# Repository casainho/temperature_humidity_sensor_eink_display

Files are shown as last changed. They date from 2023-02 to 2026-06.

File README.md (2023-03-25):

# DIY Temperature and Humidity sensor using EInk display

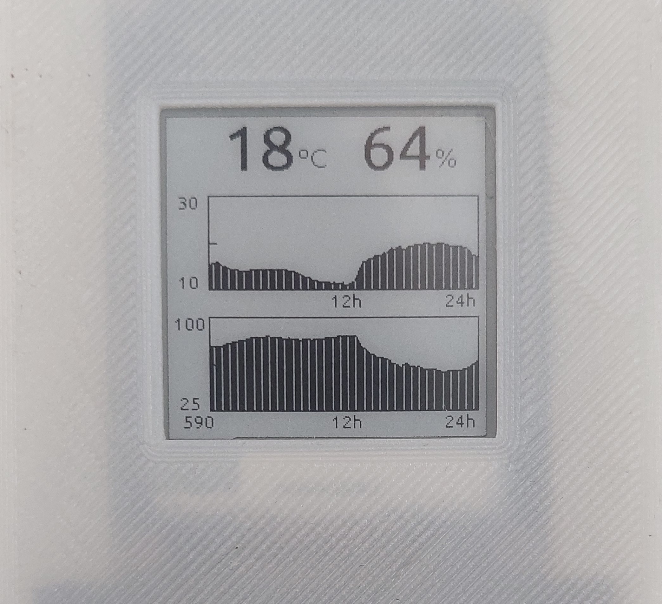
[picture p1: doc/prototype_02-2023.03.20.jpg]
[](doc/prototype_02-2023.03.20.jpg)
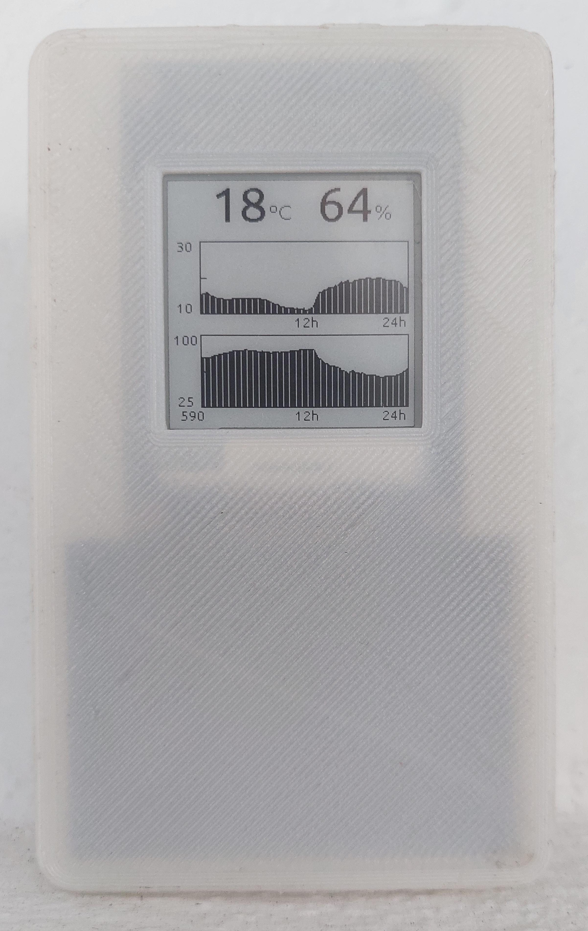
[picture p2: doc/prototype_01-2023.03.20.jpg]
[](doc/prototype_01-2023.03.20)

This is a simple DIY Temperature and Humidity sensor, with a small EInk display and (future) integration with Home Assistant.

**Features:**
  * shows the numeric value of temperature and relative humidity (measured at every 10 minutes)
  * shows two graphs with the temperature and relative humidity (measured at every 10 minutes), from the last 24h
  * PLANNED: [Send temperature and relative humidity to HomeAssistant](https://learn.adafruit.com/temperature-and-humidity-sensing-in-home-assistant-with-circuitpython)

**Main characteristics:** 
* Easy DIY, OpenSource and easy repairable
* Uses the factory calibrated temperature and humidity sensor AHT21
* The display is a 1.54 inches EInk display
* The microcontroller board is the ESP32-S2, running Pyhton (CircuitPython) firmware
* The systemn runs from a USB-C cable or from some other power supply source like 3xAAA NiMh batteries, as there is a DC-DC boost converter that supports input voltage from 1V up to 5V, and outputs a fixed 5V

All the components were bought on Aliexpress.

## Pictures

Pictures from prototype on 2023.02.22.

Showing the temperature and humidity values:<br>
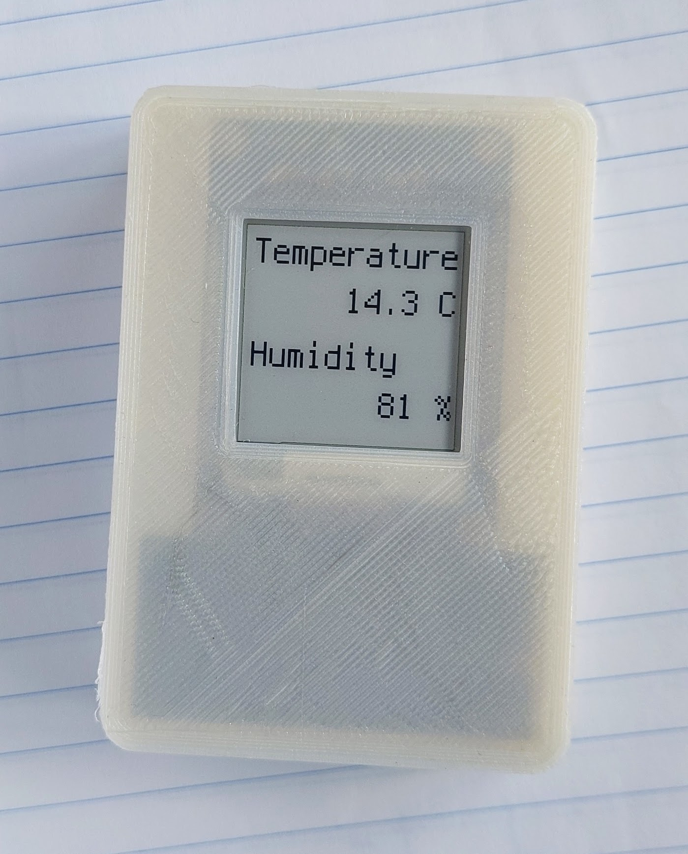
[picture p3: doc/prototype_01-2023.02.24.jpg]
[](doc/prototype_01-2023.02.24.jpg)

Details of the 3D printed enclosure:<br>
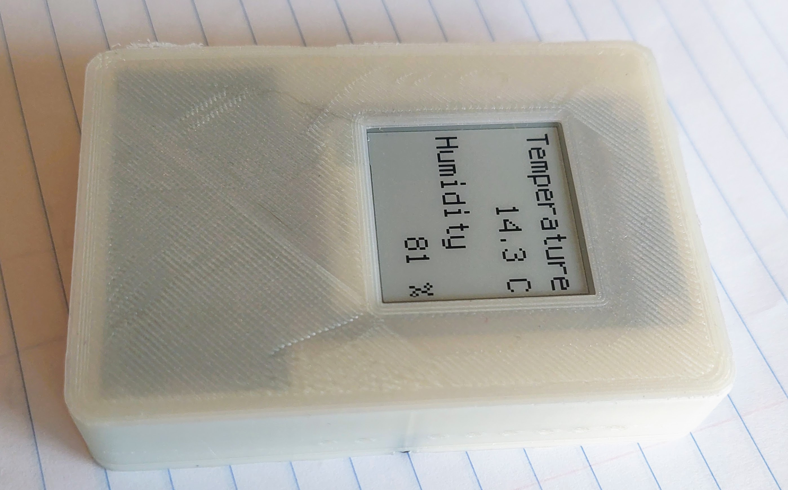
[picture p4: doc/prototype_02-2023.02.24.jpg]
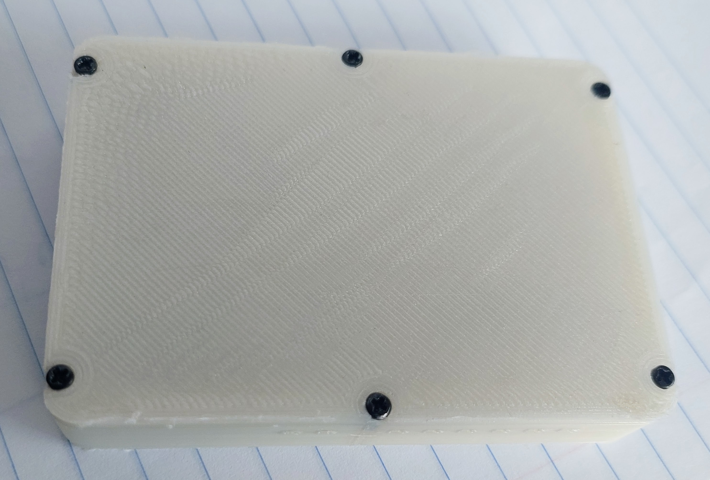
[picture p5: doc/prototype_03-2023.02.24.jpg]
[](doc/prototype_02-2023.02.24.jpg) [](doc/prototype_03-2023.02.24.jpg)

Details of the DIY electronics:<br>
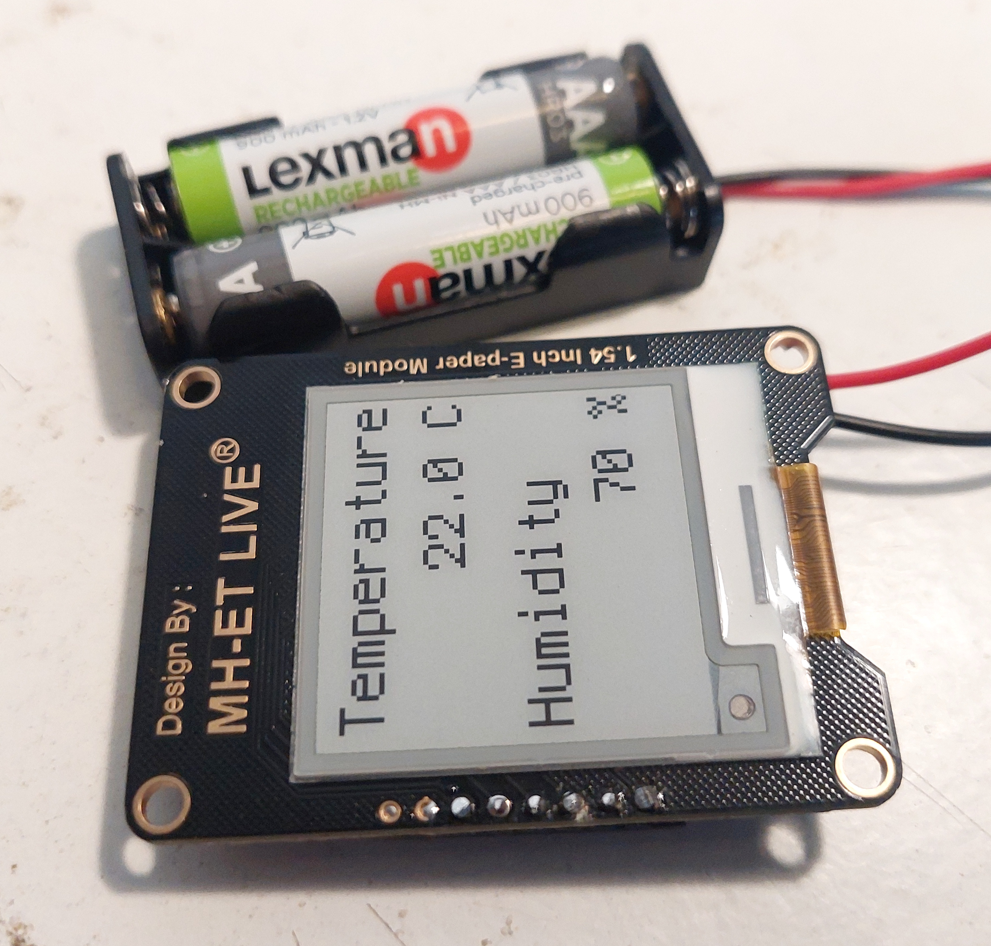
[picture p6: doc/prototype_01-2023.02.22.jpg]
[](doc/prototype_01-2023.02.22.jpg)

Details of the DIY build. Black board is the 1.54 inches EInk display, the purple board is the ESP32-S2 board (Lolin S2 Mini), the blue board is the AHT21 sensor and the green board is a DC-DC boost converter module that transforms the 2.4V from the NiMH batteries to 5V to power the ESP32-S2 board and all other components:<br>
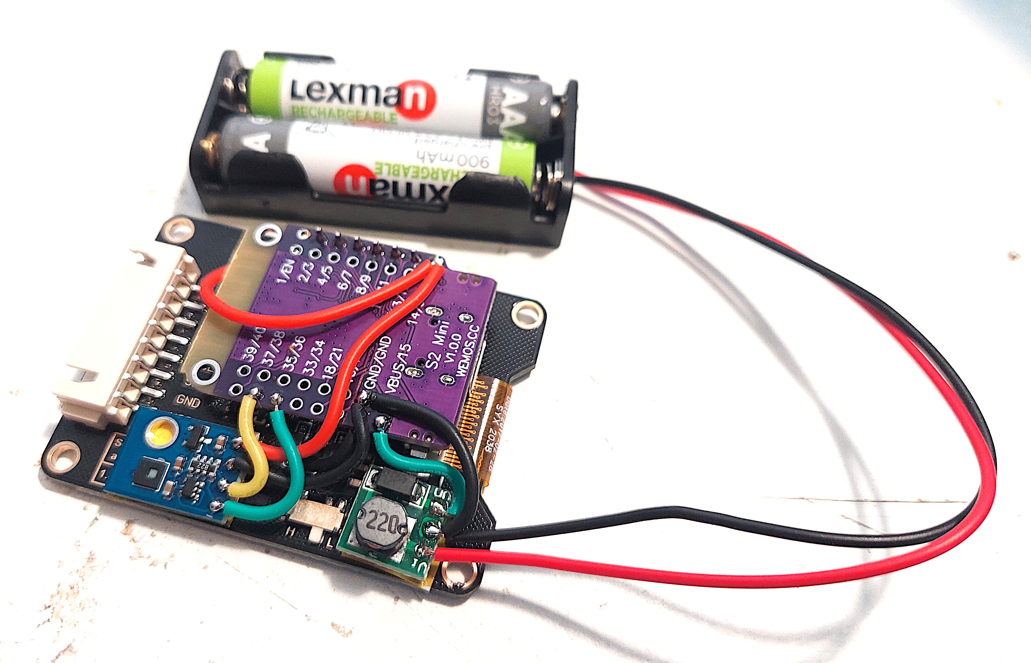
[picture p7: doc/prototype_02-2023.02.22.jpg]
[](doc/prototype_02-2023.02.22.jpg)

## Tecnhical information
* the 3D printed enclosure was designed in [FreeCAD](https://www.freecad.org/)
* the firmware is developed in [CircuitPython](https://circuitpython.org/)
* the graphs are implemented using the [uplot library](https://github.com/jposada202020/CircuitPython_uplot)

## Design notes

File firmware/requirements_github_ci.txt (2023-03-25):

adafruit-circuitpython-bitmap-font
adafruit-circuitpython-busdevice
adafruit-circuitpython-display_shapes
adafruit-circuitpython-display_text
circuitpython_uplot

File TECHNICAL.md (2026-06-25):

# DIY CO2 Monitor with ESP32-C3, SCD41 and E-Ink Display

This is a simple DIY indoor air quality monitor based on an **ESP32-C3**, a **Sensirion SCD41** sensor and a small **E-Ink display**.

The device is designed to periodically measure real CO2 concentration, temperature and relative humidity, show the latest values on the display, and then enter a low-power sleep mode to save battery.

The project is intended to be:

* easy to build;
* open source;
* repairable;
* battery powered;
* low power;
* suitable for indoor air quality monitoring.

## Features

* Measures real CO2 concentration using the Sensirion SCD41 sensor.
* Measures temperature and relative humidity.
* Shows the latest readings on a 1.54 inch E-Ink display.
* Uses an ESP32-C3 microcontroller.
* Firmware written in MicroPython.
* Designed for low-power operation using deep sleep.
* Powered from NiMH batteries through a 3.3 V DC-DC buck converter.
* Uses a DD2712SA 3.3 V buck converter module.
* Periodic measurement and display update.
* Future option: send measurements to Home Assistant.

## Main characteristics

* Microcontroller: ESP32-C3.
* Sensor: Sensirion SCD41.
* Display: 1.54 inch E-Ink display.
* Firmware: MicroPython.
* Power supply: NiMH batteries.
* DC-DC converter: DD2712SA 3.3 V buck converter.
* Operating mode: wake up, measure, update display, deep sleep.
* Typical update interval: 5 minutes.

---

# Hardware

## Hardware overview

The hardware architecture is:

```text
4x NiMH batteries
   |
   |---- Power switch
   |
DD2712SA 3.3 V buck converter
   |
   +---- ESP32-C3
   +---- Sensirion SCD41
   +---- E-Ink display
```

## Main components

| Component | Description |
| --- | --- |
| ESP32-C3 | Main microcontroller running the MicroPython firmware |
| Sensirion SCD41 | CO2, temperature and humidity sensor |
| E-Ink display | Low-power display for showing the latest values |
| DD2712SA 3.3 V | DC-DC buck converter used to generate the 3.3 V supply rail |
| 4x NiMH batteries | Rechargeable battery pack |
| Power switch | Main power switch |
| Capacitors | Used to stabilize the 3.3 V rail during current peaks |

## ESP32-C3

The project uses an **ESP32-C3** microcontroller.

The ESP32-C3 is responsible for:

* controlling the complete device;
* communicating with the SCD41 sensor using I2C;
* updating the E-Ink display;
* measuring the battery voltage, if implemented;
* managing the sleep/wake cycle;
* running the MicroPython firmware.

## Sensor

The project uses the **Sensirion SCD41** sensor.

The SCD41 measures:

* CO2 concentration, in ppm;
* temperature, in degrees Celsius;
* relative humidity, in percent.

The sensor communicates with the ESP32-C3 using I2C.

## Power supply

The device is powered from rechargeable **NiMH batteries**.

The recommended power architecture is:

```text
4x NiMH batteries
   |
DD2712SA 3.3 V buck converter
   |
3.3 V system rail
```

The DD2712SA 3.3 V module converts the battery voltage to a regulated 3.3 V supply for the ESP32-C3, SCD41 and E-Ink display.

---

# Firmware

## Firmware overview

The firmware is written in **MicroPython**.

The main firmware goal is to:

1. wake up from deep sleep;
2. initialize the required peripherals;
3. read the SCD41 sensor;
4. update the E-Ink display;
5. optionally measure battery voltage;
6. enter deep sleep again.

## Main firmware cycle

```text
Boot
  |
Initialize I2C
  |
Initialize SCD41
  |
Read CO2, temperature and humidity
  |
Read battery voltage
  |
Update E-Ink display
  |
Prepare peripherals for low-power mode
  |
Enter deep sleep
  |
Wake up after configured interval
```

## Suggested firmware structure

A modular MicroPython firmware structure is recommended:

```text
main.py
config.py
scd41.py
display.py
battery.py
power.py
```

## main.py

Main entry point.

Responsibilities:

* load configuration;
* initialize hardware;
* call the sensor reading functions;
* update the display;
* decide the next sleep interval;
* enter deep sleep.

## config.py

Project configuration.

Example:

```python
SLEEP_MINUTES = 5

I2C_SCL_PIN = 9
I2C_SDA_PIN = 8

BATTERY_CELLS = 4
LOW_BATTERY_VOLTAGE = 4.2
CRITICAL_BATTERY_VOLTAGE = 4.0

DISPLAY_ROTATION = 0
USE_WIFI = False
```

The exact I2C pins should be adjusted according to the ESP32-C3 board being used.

## scd41.py

SCD41 handling.

Responsibilities:

* initialize the SCD41 sensor;
* start measurements;
* wait until data is ready;
* read CO2, temperature and humidity;
* return a structured data object.

Example returned values:

```python
{
    "co2_ppm": 820,
    "temperature_c": 22.4,
    "humidity_percent": 54.0
}
```

## display.py

E-Ink display handling.

Responsibilities:

* initialize the display;
* draw the static layout;
* show CO2, temperature and humidity;
* show battery state;
* show warning messages;
* refresh the display.

Suggested status messages:

| CO2 level | Display status |
| ---: | --- |
| Below 800 ppm | Good |
|  800 to 1200 ppm | Ventilation recommended |
| 1200 to 2000 ppm | Poor air quality |
| Above 2000 ppm | Ventilate urgently |

## battery.py

Battery measurement and classification.

Responsibilities:

* read the ADC value;
* convert ADC reading to battery voltage;
* classify battery state;
* return battery voltage and status.

## power.py

Low-power handling.

Responsibilities:

* turn off unused peripherals when possible;
* disable Wi-Fi if not needed;
* prepare the ESP32-C3 for deep sleep;
* configure the wake-up timer.

Recommended approach:

* keep Wi-Fi disabled by default;
* keep active time as short as possible;
* avoid permanent LEDs;
* avoid unnecessary display refreshes;
* use deep sleep between measurements.

---

# Technical information

* The enclosure was designed in [FreeCAD](https://www.freecad.org/).
* The firmware is written in [MicroPython](https://micropython.org/).
* The microcontroller is an ESP32-C3.
* The display is a 1.54 inch E-Ink display.
* The CO2 sensor is the Sensirion SCD41.
* The power converter is the DD2712SA 3.3 V buck converter.
* The system is designed for periodic measurements and low-power sleep operation.

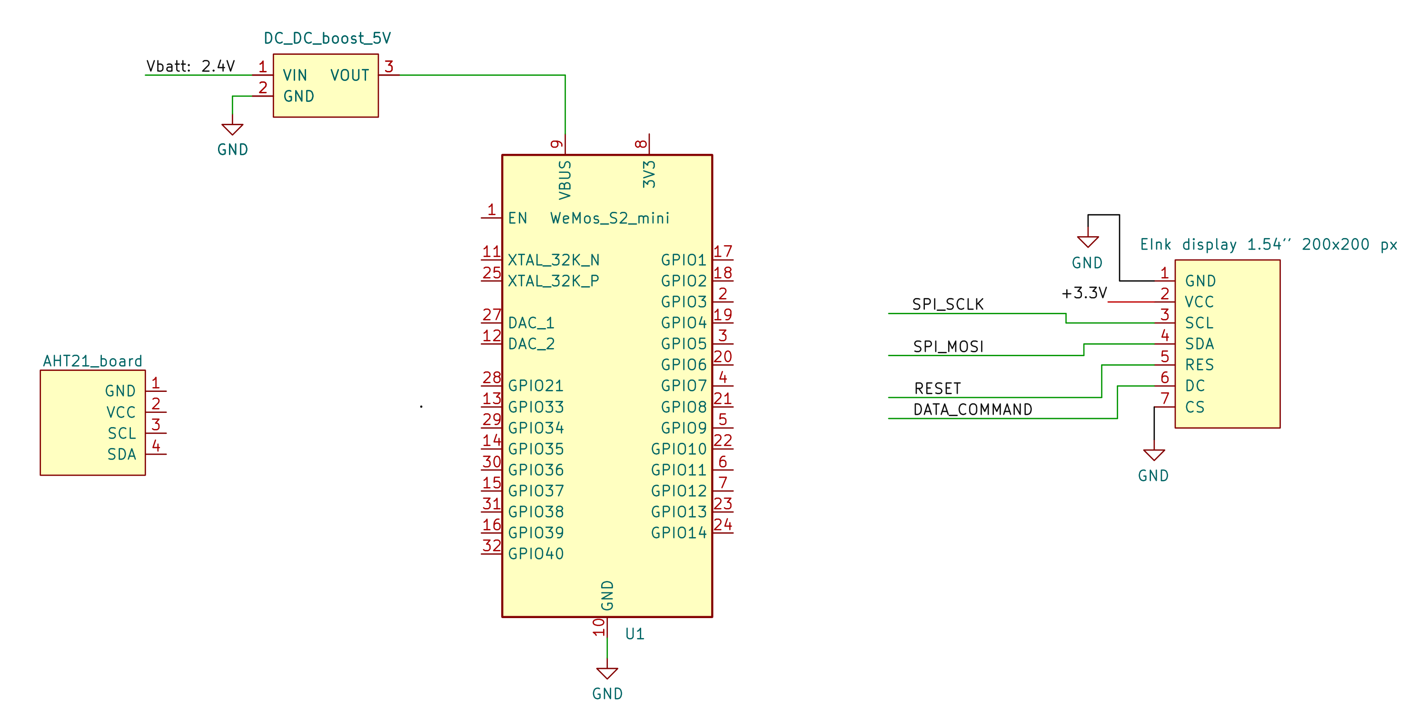
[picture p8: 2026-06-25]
hardware/schematic.png

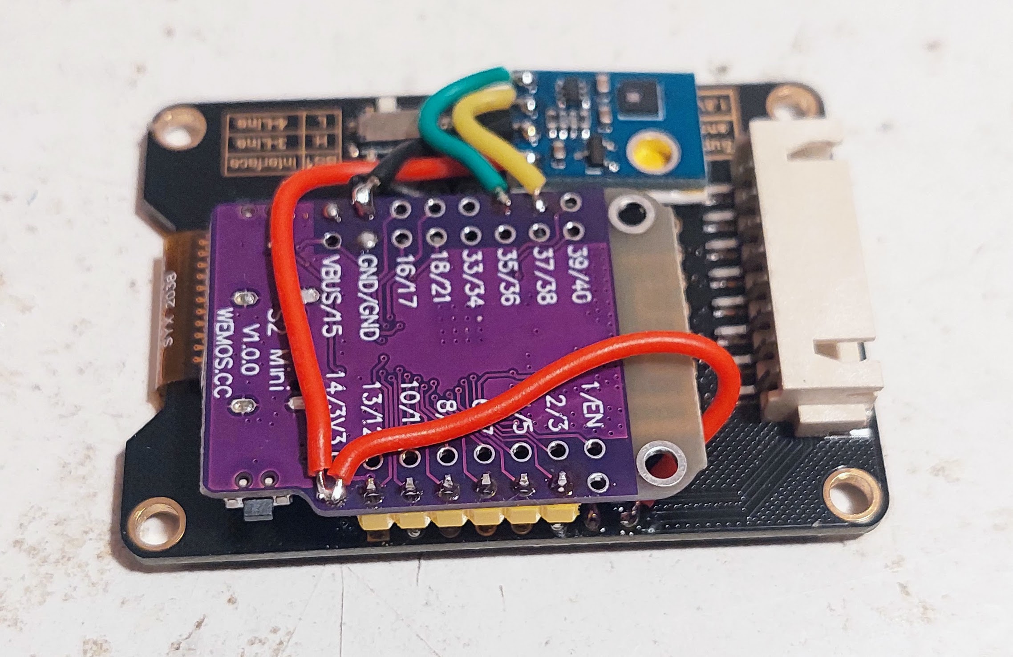
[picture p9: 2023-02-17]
doc/prototype_04-2023.02.17.jpg

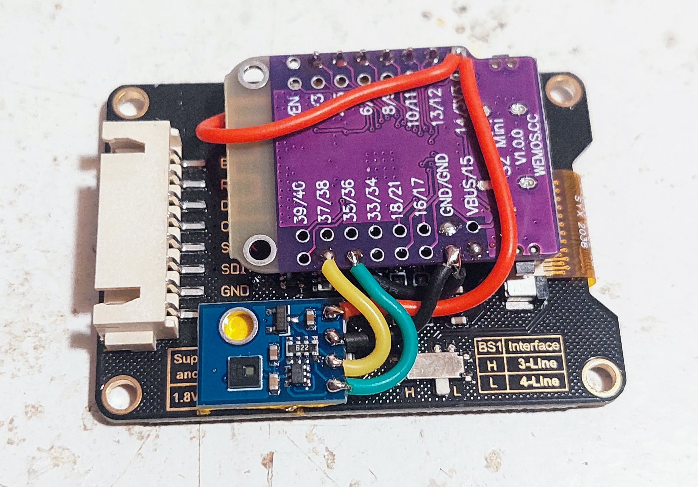
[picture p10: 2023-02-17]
doc/prototype_03-2023.02.17.jpg

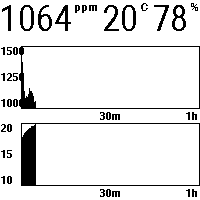
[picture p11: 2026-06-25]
latest_screen.png

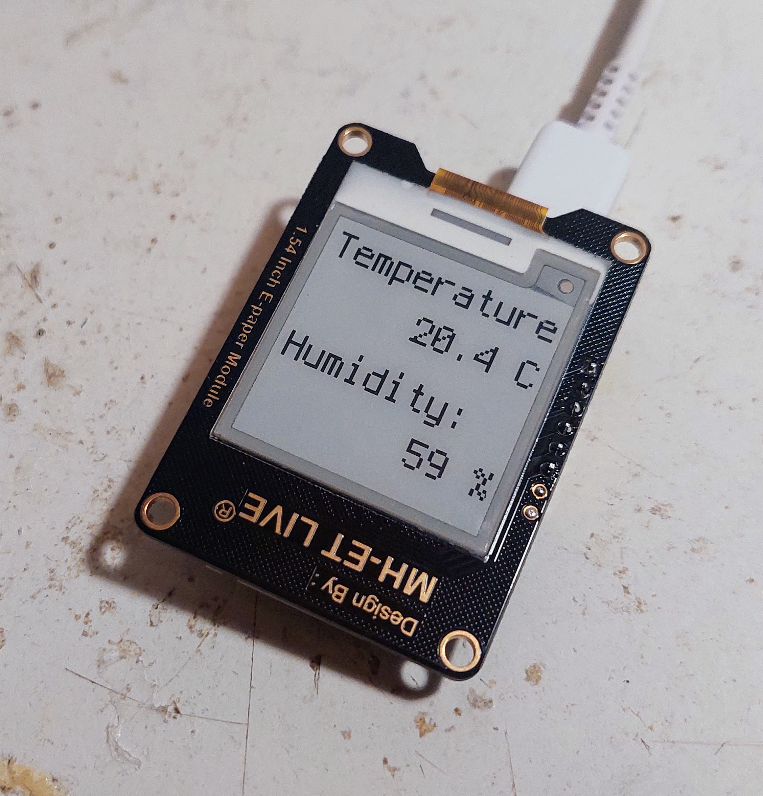
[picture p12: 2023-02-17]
doc/prototype_05-2023.02.17.jpg

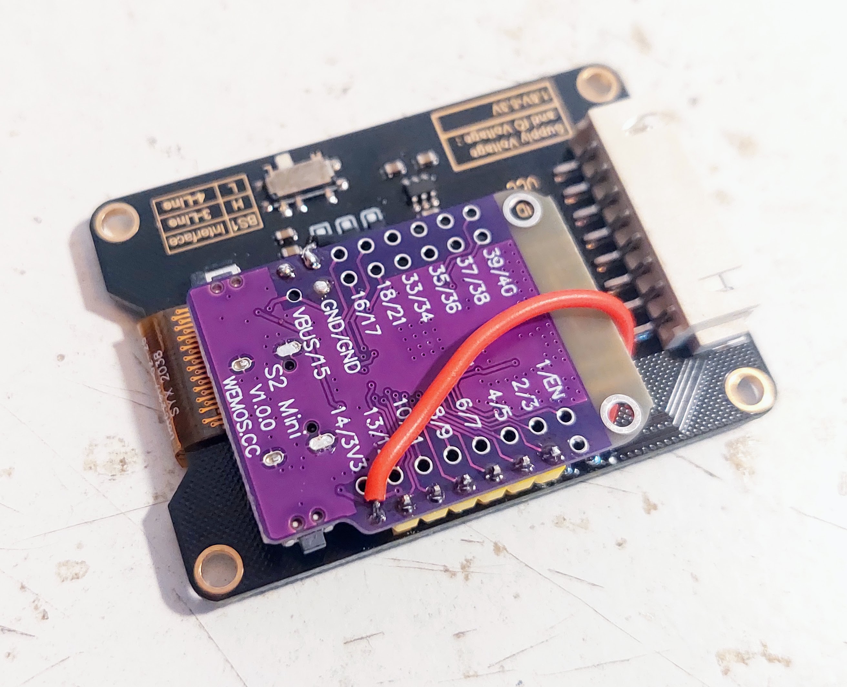
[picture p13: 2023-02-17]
doc/prototype_02-2023.02.17.jpg

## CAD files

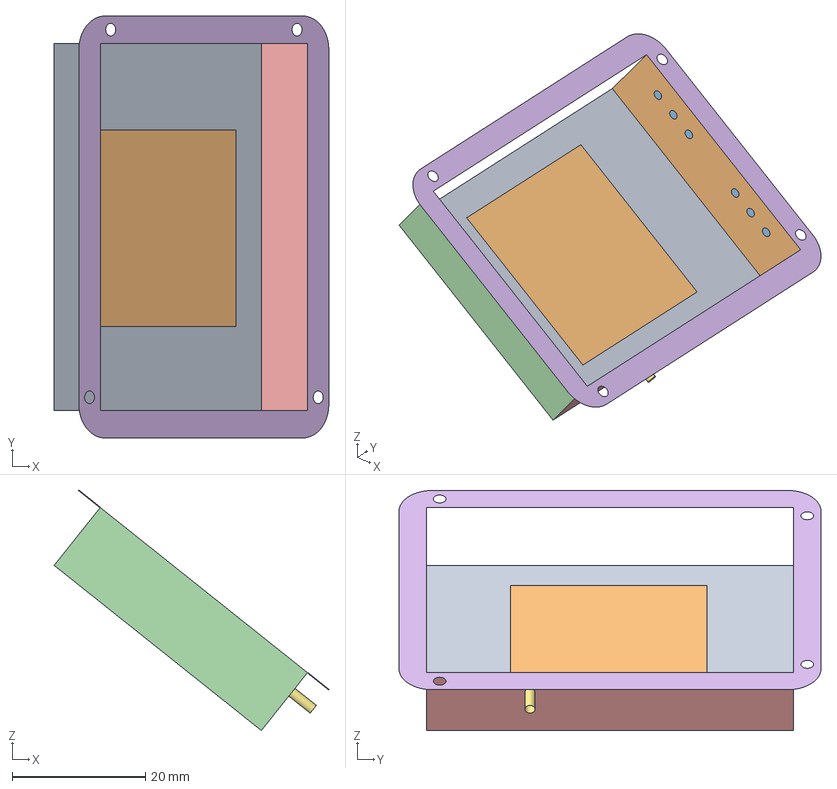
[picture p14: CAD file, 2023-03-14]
3d_print_enclosure/sensor-assembly3.FCStd
41.2 x 63.3 x 36.0 mm
_Element
_Element001
_Element003
_Element006
_Element008
_Element019
_Element028
_Element035
_Element036
_Element041
_Element042
_Element043

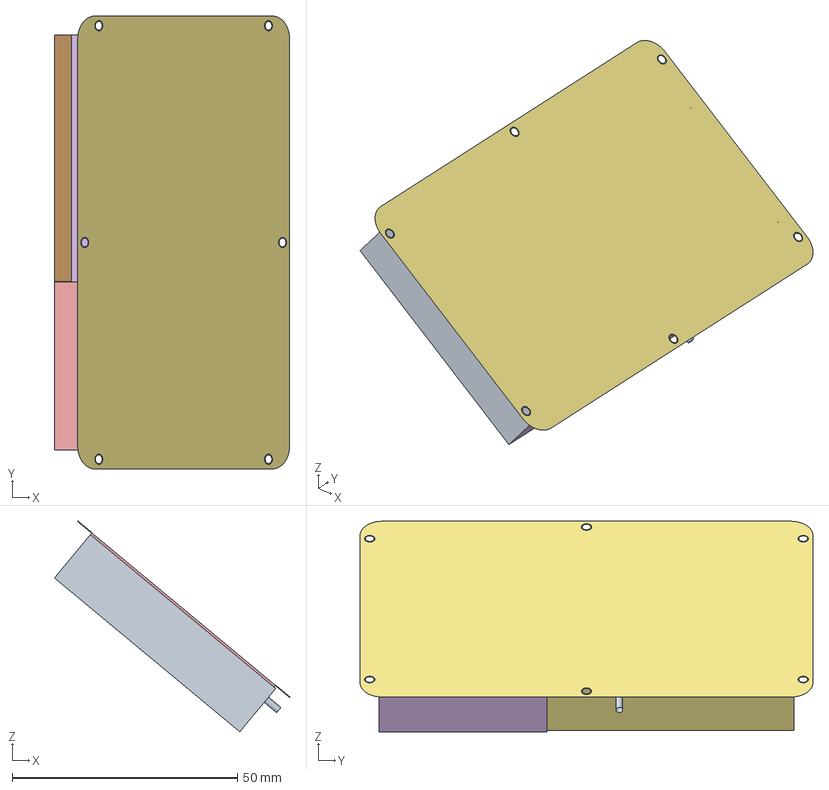
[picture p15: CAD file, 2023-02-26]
3d_print_enclosure/enclosure_with_3x_aaa_nihm/sensor-assembly3.FCStd
52.2 x 100.6 x 46.8 mm
_Element
_Element001
_Element002
_Element003
_Element006
_Element007
_Element008
_Element009
_Element010
_Element012
_Element014
_Element015
_Element016
_Element017
_Element018
_Element019
_Element028
_Element035
_Element036
_Element041
_Element042

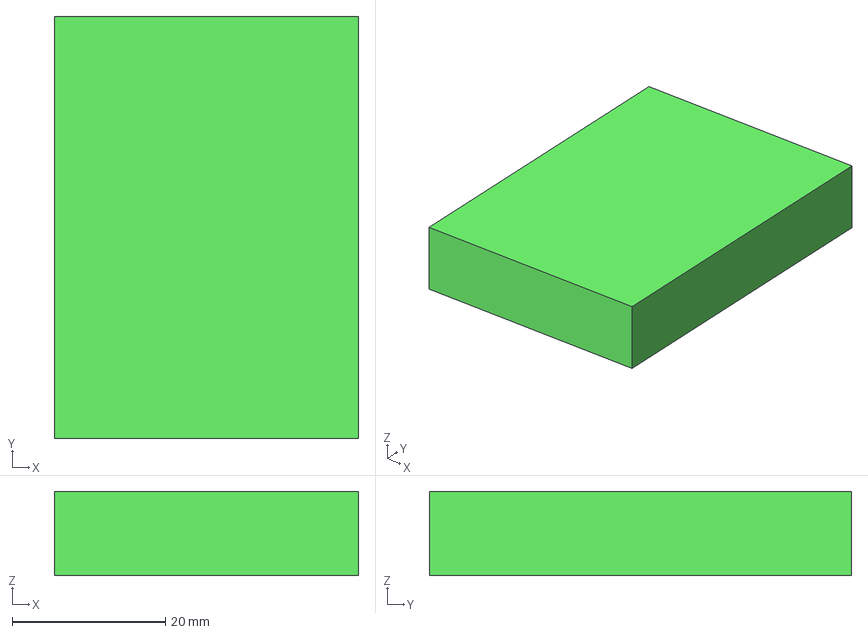
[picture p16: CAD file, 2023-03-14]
3d_print_enclosure/electronics.FCStd
39.8 x 55.1 x 11.0 mm
electronics x 2

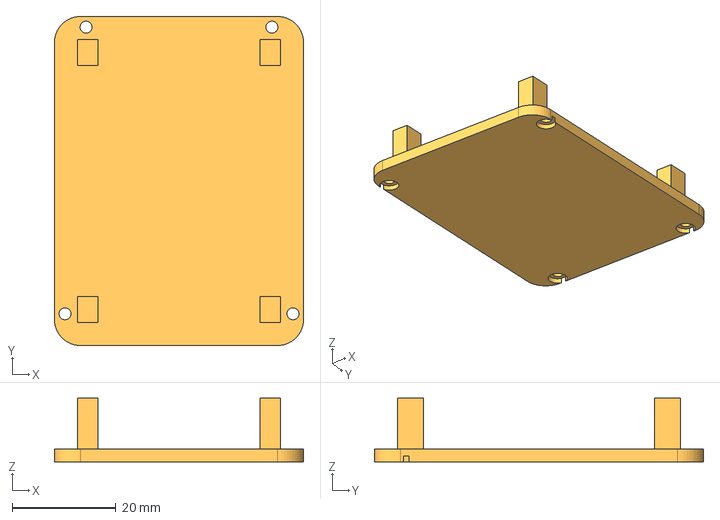
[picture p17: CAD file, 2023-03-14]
3d_print_enclosure/cover.FCStd
48.0 x 63.3 x 12.3 mm
cover x 2

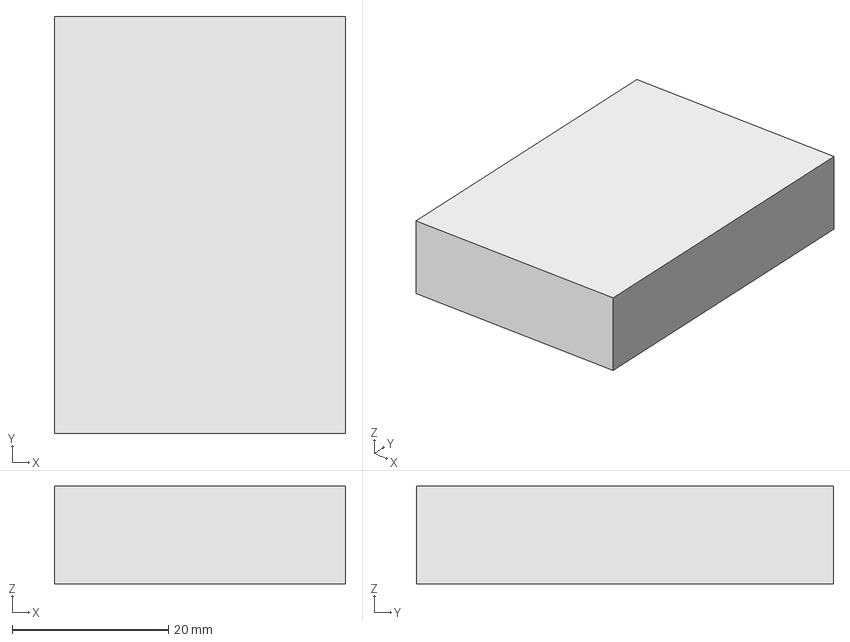
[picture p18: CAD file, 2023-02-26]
3d_print_enclosure/enclosure_with_3x_aaa_nihm/battery.FCStd
37.3 x 53.5 x 12.5 mm
battery x 2

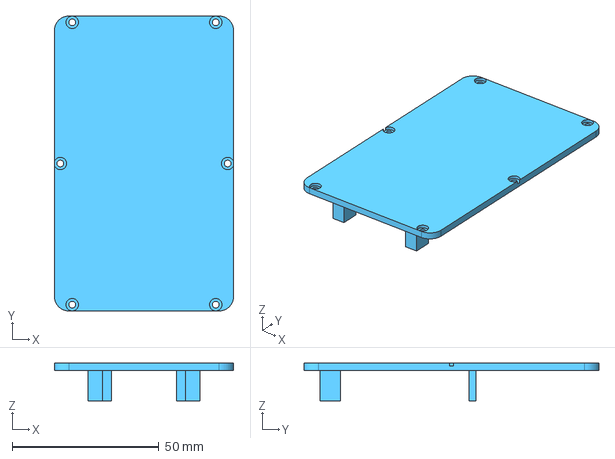
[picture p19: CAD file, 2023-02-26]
3d_print_enclosure/enclosure_with_3x_aaa_nihm/cover.FCStd
61.1 x 100.6 x 13.0 mm
cover x 2

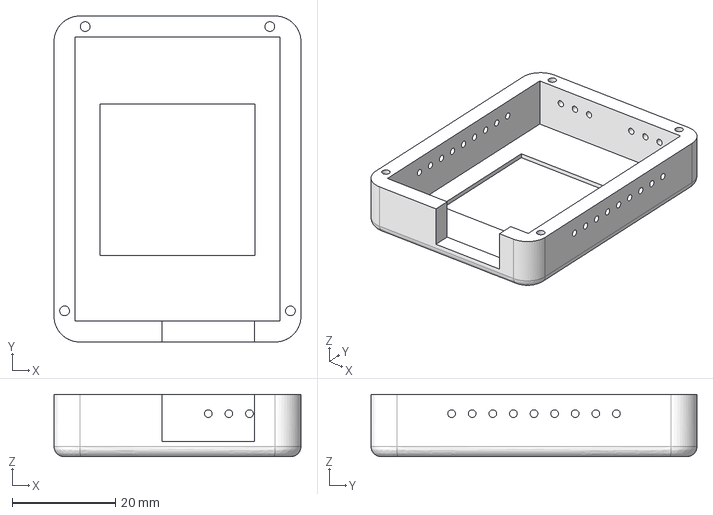
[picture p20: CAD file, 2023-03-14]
3d_print_enclosure/enclosure.FCStd
48.0 x 63.3 x 12.1 mm
enclosure x 2

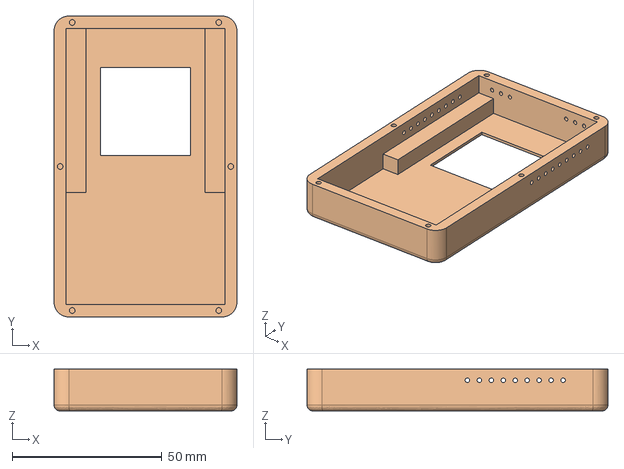
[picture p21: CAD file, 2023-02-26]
3d_print_enclosure/enclosure_with_3x_aaa_nihm/enclosure.FCStd
61.1 x 100.6 x 14.0 mm
enclosure x 2

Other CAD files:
3d_print_enclosure/enclosure_with_3x_aaa_nihm/electronics.FCStd
3d_print_enclosure/cover.amf
3d_print_enclosure/enclosure.amf
3d_print_enclosure/enclosure_with_3x_aaa_nihm/cover.amf
3d_print_enclosure/enclosure_with_3x_aaa_nihm/enclosure.amf

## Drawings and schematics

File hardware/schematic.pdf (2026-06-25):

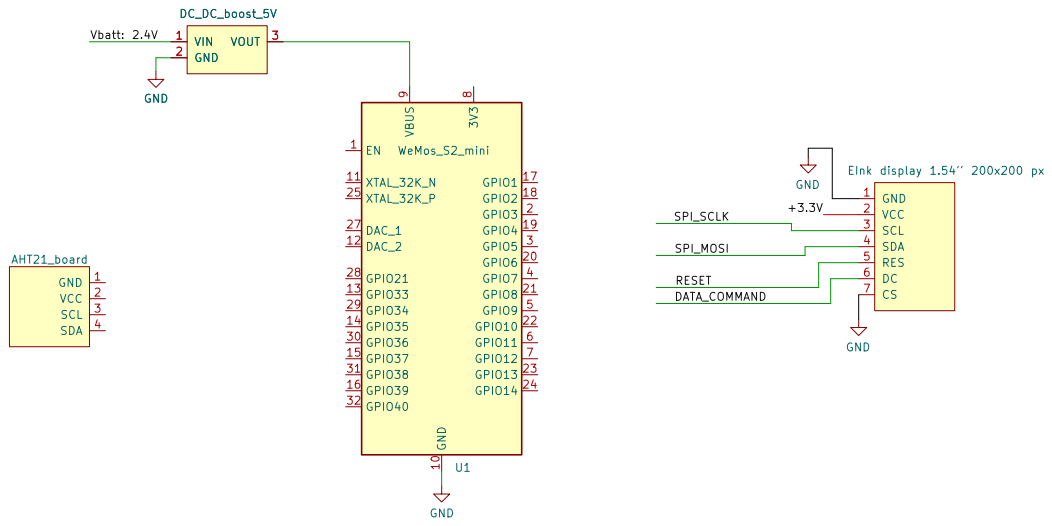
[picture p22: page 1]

EInk display 1.54'' 200x200 px GND

Size: A3 | Rev: | F Date:
KiCad E.D.A. 10.0.3 | Id: 1/1

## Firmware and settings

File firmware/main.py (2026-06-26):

import time
import machine
import ubinascii
from machine import Pin, SPI

# ---------------------------------------------------------------------------
# Pin assignments for ESP32-S2 mini — adjust to match your board wiring
# ---------------------------------------------------------------------------
I2C_SCL  = 37   # sensor SCL
I2C_SDA  = 35   # sensor SDA

SPI_CLK   = 5   # SSD1681 CLK
SPI_MOSI  = 3   # SSD1681 MOSI (SDI)
EINK_CS   = 7   # SSD1681 chip select
EINK_DC   = 9   # SSD1681 data/command
EINK_RST  = 11  # SSD1681 reset
EINK_BUSY = 12  # SSD1681 busy (input)

# ---------------------------------------------------------------------------
# Imports (sensor module initialises RTC memory on import)
# ---------------------------------------------------------------------------
from sensor import _mem, _is_deepsleep_wake, _SENSOR_MEM_OFFSET, Sensor
from scale import (
    round_to_int,
    get_co2_y_values, get_temperature_y_values,
    get_y_half_scale_value,
)
from draw import draw_text, text_width, draw_graph, BLACK, WHITE
from fonts import robotobold40 as font_top     # top-row values (height 40 px)
from fonts import robotobold18 as font_medium  # units / graph labels (height 18 px)
from fonts import robotobold12 as font_small   # graph labels (height 11 px)
from ssd1681 import SSD1681

_t_start = time.ticks_ms()
SENSOR_SETTLE_MS = 500
DISPLAY_SETTLE_MS = 1000
REFRESH_INTERVAL_MS = 20_000
DEBUG_DUMP_FRAMEBUFFER = True
DUMP_CHUNK_SIZE = 64
WARMUP_READS = 4
GRAPH_STORE_EVERY = 8  # store 1 graph point every 8 cycles (8 × 20 s = 160 s → 180 pts = 8 h)

# ---------------------------------------------------------------------------
# Wake counter (bytes 0-2 of shared RTC memory)
# ---------------------------------------------------------------------------
if _is_deepsleep_wake():
    counter = (_mem[0] << 16) | (_mem[1] << 8) | _mem[2]
else:
    counter = 0
counter += 1
_mem[0] = (counter >> 16) & 0xFF
_mem[1] = (counter >> 8) & 0xFF
_mem[2] = counter & 0xFF

# ---------------------------------------------------------------------------
# Sensor and display objects are reused across refreshes.
sensor = Sensor(I2C_SCL, I2C_SDA, _SENSOR_MEM_OFFSET, i2c_bus=1)

# ---------------------------------------------------------------------------
# Derived layout positions based on actual font heights
# ---------------------------------------------------------------------------
TOP_H = font_top.height()      # 40 px
MED_H = font_medium.height()   # 18 px
SM_H  = font_small.height()    # 11 px

TOP_Y     = 0                         # top value row
TOP_GY    = 46                        # CO2 graph top
TOP_GH    = 63                        # CO2 graph height
BOT_GY    = 123                       # temperature graph top
BOT_GH    = 63                        # temperature graph height
GX        = 27                        # graph left edge (space for y-axis labels)
GW        = 173                       # graph width including box
X12H      = GX + GW // 2              # true midpoint of the graph x-axis
X24H      = 198                       # original-style right edge label position
X_STEPS   = 179                       # fixed x-axis slots for 180 stored points
BOTTOM    = 199                       # bottom text row
Y_LABEL_X  = GX - 2                   # right edge for y-axis labels


def _draw_y_label(fb, value, y):
    text = str(value)
    draw_text(fb, font_small, text, Y_LABEL_X - text_width(font_small, text), y)


def _x_label_for_zero_center(font, text, center_x):
    zero_center = text_width(font, text[0]) + text_width(font, text[1]) // 2
    return center_x - zero_center


def _draw_screen(fb, co2, temp, humid, co2_data, co2_y_min, co2_y_max,
                 temp_data, temp_y_min, temp_y_max, counter_value):
    fb.fill(WHITE)

    # Top row: CO2, temperature, humidity
    co2_str = str(min(round_to_int(co2), 9999))
    temp_str = str(min(round_to_int(temp), 99))
    humid_str = str(min(round_to_int(humid), 99))
    # Compute each group width and distribute two equal gaps between the three groups.
    UNIT_GAP = 2
    w_co2   = text_width(font_top, co2_str)
    w_temp  = text_width(font_top, temp_str)
    w_humid = text_width(font_top, humid_str)
    temp_unit = 'C'
    ppm_unit_w = max(
        text_width(font_small, 'pp'),
        text_width(font_small, 'm'),
    )
    w_co2_group   = w_co2   + UNIT_GAP + ppm_unit_w
    w_temp_group  = w_temp  + UNIT_GAP + text_width(font_small, temp_unit)
    w_humid_group = w_humid + UNIT_GAP + text_width(font_small, '%')
    gap = max(0, (200 - w_co2_group - w_temp_group - w_humid_group) // 2)

    co2_x   = 0
    temp_x  = w_co2_group + gap
    humid_x = temp_x + w_temp_group + gap
    unit_y  = TOP_Y + TOP_H - SM_H - 4
    temp_unit_y = unit_y - 4

    draw_text(fb, font_top, co2_str, co2_x, TOP_Y)
    ppm_x = co2_x + w_co2 + UNIT_GAP
    draw_text(fb, font_small, 'pp', ppm_x, temp_unit_y - (SM_H + 1))
    draw_text(fb, font_small, 'm', ppm_x, temp_unit_y)

    draw_text(fb, font_top, temp_str, temp_x, TOP_Y)
    draw_text(fb, font_small, temp_unit, temp_x + w_temp + UNIT_GAP, temp_unit_y)

    draw_text(fb, font_top, humid_str, humid_x, TOP_Y)
    draw_text(fb, font_small, '%', humid_x + w_humid + UNIT_GAP, temp_unit_y)

    # First graph: CO2
    co2_y_mid = get_y_half_scale_value(co2_y_max, co2_y_min)
    _draw_y_label(fb, co2_y_max, TOP_GY)
    _draw_y_label(fb, co2_y_mid, TOP_GY + TOP_GH // 2 - SM_H // 2)
    _draw_y_label(fb, co2_y_min, TOP_GY + TOP_GH - SM_H)
    draw_graph(fb, GX, TOP_GY, GW, TOP_GH, co2_data, co2_y_min, co2_y_max, x_steps=X_STEPS)
    draw_text(fb, font_small, '4h', _x_label_for_zero_center(font_small, '4h', X12H), TOP_GY + TOP_GH + 2)
    draw_text(fb, font_small, '8h', X24H - text_width(font_small, '8h'), TOP_GY + TOP_GH + 2)

    # Second graph: temperature
    temp_y_mid = get_y_half_scale_value(temp_y_max, temp_y_min)
    _draw_y_label(fb, temp_y_max, BOT_GY)
    _draw_y_label(fb, temp_y_mid, BOT_GY + BOT_GH // 2 - SM_H // 2)
    _draw_y_label(fb, temp_y_min, BOT_GY + BOT_GH - SM_H)
    draw_graph(fb, GX, BOT_GY, GW, BOT_GH, temp_data, temp_y_min, temp_y_max, x_steps=X_STEPS)
    draw_text(fb, font_small, '4h', _x_label_for_zero_center(font_small, '4h', X12H), BOT_GY + BOT_GH + 2)
    draw_text(fb, font_small, '8h', X24H - text_width(font_small, '8h'), BOT_GY + BOT_GH + 2)

    # Bottom-left cycle counter
    draw_text(fb, font_small, str(counter_value), 0, BOTTOM)


def _dump_framebuffer(display_obj, counter_value):
    if not DEBUG_DUMP_FRAMEBUFFER:
        return

    buf = display_obj._buf
    print('FB_BEGIN counter={} len={}'.format(counter_value, len(buf)))
    for offset in range(0, len(buf), DUMP_CHUNK_SIZE):
        chunk = buf[offset:offset + DUMP_CHUNK_SIZE]
        print('{:04x}: {}'.format(offset, ubinascii.hexlify(chunk).decode()))
    print('FB_END counter={}'.format(counter_value))


# ---------------------------------------------------------------------------
# Initialise display
# ---------------------------------------------------------------------------
time.sleep_ms(DISPLAY_SETTLE_MS)
spi = SPI(1,
          baudrate=20_000_000,
          polarity=0, phase=0,
          sck=Pin(SPI_CLK),
          mosi=Pin(SPI_MOSI),
          miso=None)

display = SSD1681(
    spi,
    cs=Pin(EINK_CS, Pin.OUT),
    dc=Pin(EINK_DC, Pin.OUT),
    rst=Pin(EINK_RST, Pin.OUT),
    busy=Pin(EINK_BUSY, Pin.IN),
)

_CAL_FLAG = '/cal_flag'

def _cal_flag_value():
    try:
        with open(_CAL_FLAG) as f:
            return int(f.read().strip())
    except Exception:
        return 1

def _set_cal_flag(value):
    with open(_CAL_FLAG, 'w') as f:
        f.write(str(value))

if _cal_flag_value() == 0:
    sensor.calibrate_co2()
    _set_cal_flag(1)
    display.fb.fill(WHITE)
    msg = 'CO2 calibrated'
    draw_text(display.fb, font_medium, msg,
              max(0, (200 - text_width(font_medium, msg)) // 2), 91)
    display.show()
    time.sleep_ms(20_000)

sample_count = 0
while True:
    cycle_start = time.ticks_ms()

    counter += 1
    _mem[0] = (counter >> 16) & 0xFF
    _mem[1] = (counter >> 8) & 0xFF
    _mem[2] = counter & 0xFF

    if sample_count < WARMUP_READS or (sample_count % GRAPH_STORE_EVERY) != 0:
        sensor.read()
    else:
        sensor.read_and_store()
    sample_count += 1
    time.sleep_ms(SENSOR_SETTLE_MS)

    co2   = sensor.co2
    temp  = sensor.temperature
    humid = sensor.humidity

    co2_data,   co2_max,   co2_min,   _ = sensor.historic_data_co2
    temp_data,  temp_max,  temp_min,  _ = sensor.historic_data_temperature

    co2_y_max,  co2_y_min  = get_co2_y_values(co2_max or co2, co2_min or co2)
    temp_y_max, temp_y_min = get_temperature_y_values(temp_max or temp, temp_min or temp)

    _draw_screen(display.fb, co2, temp, humid, co2_data, co2_y_min, co2_y_max,
                 temp_data, temp_y_min, temp_y_max, counter)

    display.show()
    _dump_framebuffer(display, counter)

    elapsed_ms = time.ticks_diff(time.ticks_ms(), cycle_start)
    time.sleep_ms(max(0, REFRESH_INTERVAL_MS - elapsed_ms))

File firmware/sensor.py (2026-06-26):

# RTC memory layout (1101 bytes used, 1104 bytes reserved):
#   [0..2]     counter (3 bytes)
#   [3..368]   CO2 ring buffer   (6 header + 360 data)
#   [369..734] Temp ring buffer  (6 header + 360 data)
#   [735..1100] Humid ring buffer (6 header + 360 data)

_RTC_MEM_SIZE = 1104
_SENSOR_MEM_OFFSET = 3  # first 3 bytes reserved for the wake counter

try:
    import machine
    from scd41 import SCD41

    _rtc = machine.RTC()

    def _is_deepsleep_wake():
        return machine.reset_cause() == machine.DEEPSLEEP_RESET

    def _load_mem():
        raw = _rtc.memory()
        if _is_deepsleep_wake() and len(raw) >= _RTC_MEM_SIZE:
            return bytearray(raw)
        return bytearray(_RTC_MEM_SIZE)

    def _save_mem(data):
        _rtc.memory(data)

    _testing = False

except Exception:
    print("sensor.py: running in test mode")
    _testing = True

    def _is_deepsleep_wake():
        return False

    def _load_mem():
        return bytearray(_RTC_MEM_SIZE)

    def _save_mem(data):
        pass


_mem = _load_mem()


class MemoryForSensorData:
    """Circular ring buffer backed by the shared RTC memory bytearray."""

    def __init__(self, offset_address, capacity_x2, scale=10):
        self._memory = _mem
        self._scale = scale
        self._offset_address_initial = offset_address
        self._offset_address = offset_address
        self._capacity_x2 = capacity_x2

        self._current_size = 0
        self._head_x2 = 0
        self._tail_x2 = 0

        if _is_deepsleep_wake():
            m = self._memory
            o = offset_address
            self._current_size = (m[o] << 8) | m[o + 1]
            self._head_x2 = (m[o + 2] << 8) | m[o + 3]
            self._tail_x2 = (m[o + 4] << 8) | m[o + 5]

        self._offset_address += 6
        self._max_value = None
        self._min_value = None

    @property
    def sensor_memory_offset(self):
        return self._offset_address + self._capacity_x2

    def add(self, value):
        cap = self._capacity_x2
        o = self._offset_address

        if self._tail_x2 == self._head_x2 and (self._current_size * 2) == cap:
            self._head_x2 = (self._head_x2 + 2) % cap

        self._memory[o + self._tail_x2]     = (value >> 8) & 0xFF
        self._memory[o + self._tail_x2 + 1] = value & 0xFF
        self._tail_x2 = (self._tail_x2 + 2) % cap

        if (self._current_size * 2) < cap:
            self._current_size += 1

        oi = self._offset_address_initial
        self._memory[oi]     = (self._current_size >> 8) & 0xFF
        self._memory[oi + 1] = self._current_size & 0xFF
        self._memory[oi + 2] = (self._head_x2 >> 8) & 0xFF
        self._memory[oi + 3] = self._head_x2 & 0xFF
        self._memory[oi + 4] = (self._tail_x2 >> 8) & 0xFF
        self._memory[oi + 5] = self._tail_x2 & 0xFF

    @property
    def values(self):
        if self._current_size < 1:
            return []
        data = [0.0] * self._current_size
        cap = self._capacity_x2
        o = self._offset_address
        head_x2 = self._head_x2
        self._max_value = None
        self._min_value = None
        for i in range(self._current_size):
            raw = (self._memory[o + head_x2] << 8) | (self._memory[o + head_x2 + 1] & 0xFF)
            v = raw / self._scale
            data[i] = v
            if self._max_value is None or v > self._max_value:
                self._max_value = v
            if self._min_value is None or v < self._min_value:
                self._min_value = v
            head_x2 = (head_x2 + 2) % cap
        return data

    @property
    def len(self):
        return self._current_size

    @property
    def max(self):
        return self._max_value

    @property
    def min(self):
        return self._min_value


class Sensor:
    def __init__(self, i2c_scl_pin, i2c_sda_pin, sleep_memory_offset, i2c_bus=1):
        if not _testing:
            i2c = machine.I2C(i2c_bus,
                              scl=machine.Pin(i2c_scl_pin),
                              sda=machine.Pin(i2c_sda_pin),
                              freq=100_000)
            self._sensor = SCD41(i2c)
        else:
            self._sensor = None

        self._last_co2   = 0
        self._last_temp  = 0.0
        self._last_humid = 0.0

        if not _testing:
            self._sensor.set_asc_enabled(False)

        # CO2 stored as raw ppm integer (scale=1)
        self._data_co2   = MemoryForSensorData(sleep_memory_offset, 180 * 2, scale=1)
        sleep_memory_offset = self._data_co2.sensor_memory_offset

        # Temperature stored ×10 so one decimal place survives integer storage
        self._data_temp  = MemoryForSensorData(sleep_memory_offset, 180 * 2, scale=10)
        sleep_memory_offset = self._data_temp.sensor_memory_offset

        # Humidity stored ×10
        self._data_humid = MemoryForSensorData(sleep_memory_offset, 180 * 2, scale=10)

    def read(self):
        co2, temp, humid = self._sensor.read()
        self._last_co2   = int(co2)
        self._last_temp  = round(temp, 1)
        self._last_humid = round(humid, 1)

    def read_and_store(self):
        self.read()

        self._data_co2.add(self._last_co2)
        self._data_temp.add(int(self._last_temp * 10))
        self._data_humid.add(int(self._last_humid * 10))

        _save_mem(_mem)

    def calibrate_co2(self, target_ppm=400):
        self._sensor.perform_forced_recalibration(target_ppm)

    @property
    def co2(self):
        return self._last_co2

    @property
    def temperature(self):
        return self._last_temp

    @property
    def humidity(self):
        return self._last_humid

    @property
    def historic_data_co2(self):
        v = self._data_co2.values
        return v, self._data_co2.max, self._data_co2.min, self._data_co2.len

    @property
    def historic_data_temperature(self):
        v = self._data_temp.values
        return v, self._data_temp.max, self._data_temp.min, self._data_temp.len

    @property
    def historic_data_humidity(self):
        v = self._data_humid.values
        return v, self._data_humid.max, self._data_humid.min, self._data_humid.len

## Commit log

2023-02-14 Added initial hardware
    [schematic.kicad_sch]
2023-02-14 Added correct ESP32-S2 symbol
    [schematic.kicad_sch]
2023-02-21 Added circuitpython binary that is installed on the board
2023-02-23 Added 3D printed model for the enclosure. Added pictures of current prototype - electronics are now fully tested
    [battery.FCStd, electronics .FCStd, enclosure.FCStd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]
2023-02-24 Final version of the 3D printed enclosure. Added pictures of latest prototype with final enclosure.
    [battery.FCStd, cover.FCStd, cover.amf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]
2023-02-25 Disable wifi to try save power
2023-02-26 Added alarm_sleep for low power mode
2023-02-26 Added LED off to save power
2023-02-26 Disable wifi radio makes the board not booting with a 2 x AAA NiMh batteries
2023-02-26 finished the power optmization
2023-02-26 Changed 3D printed file for 3 x AAA batteries as 2 X AAA batteries were not enought
    [battery.FCStd, cover.FCStd, cover.amf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]
2023-03-08 Sensor data graph is now stored on the sleep memory
2023-03-09 Sensors data now have max and min values. Added custom fonts
2023-03-14 Added the 3D printed enclosure power with a USB-C cable, no batteries. Latest changes for uplot
    [battery.FCStd, cover.FCStd, cover.amf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]
2023-03-14 Corrected min and max of sensor
    [main.py, sensor.py]
2023-03-20 Hope to correct issue with graph only update after 48h. Final design. Latest libraries
    [main.py, sensor.py]
2023-03-20 Added recent photos of current prototype showing the working plot graphs
2023-03-25 Added initial tests to sensor.py
2023-03-25 Improved tests. Found a bug on the code
    [sensor.py]
2023-04-09 solved issue where stored values were placed at wrong address
    [main.py, sensor.py]
2026-06-15 Firmware is now micropython. Changed to CO2 sensor, that also measures temp and hum
2026-06-25 Sync latest firmware from ESP32-S2 board
    - main.py: updated pin assignments for ESP32-S2 mini, switched from
    deep sleep to continuous while-loop (20 s refresh), redesigned layout
    with robotobold40 font, x-axis labels changed from 24h to 1h,
    added warmup reads and debug framebuffer dump
    - sensor.py: added i2c_bus parameter, increased RTC buffer to 360
    entries per sensor, separated read() from read_and_store()
    - draw.py: draw_graph() accepts x_steps parameter instead of hardcoded 143
    - scale.py: refactored get_co2_y_values() with snap helpers and levels
    table up to 9999 ppm
    [draw.py, main.py, scale.py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]
2026-06-25 Add remaining local changes before merge with remote
    Stage font files, hardware schematics, scd41/ssd1681 drivers,
    updated requirements and test files, remove legacy lib/ dependencies.
2026-06-26 Added calibration of CO2 value with a persistent flag
